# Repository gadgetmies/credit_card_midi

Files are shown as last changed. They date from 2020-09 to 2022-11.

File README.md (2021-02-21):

# Credit Card MIDI Controllers

Arduino based, credit card sized, capacitive touch sensing MIDI controllers.

Very much a work in progress. Contributions welcomed 😊!

USB board connector design by @Pinuct: https://github.com/Pinuct/Eagle_PCB_USB_connectors

More info: https://hackaday.io/project/177099-credit-card-midi

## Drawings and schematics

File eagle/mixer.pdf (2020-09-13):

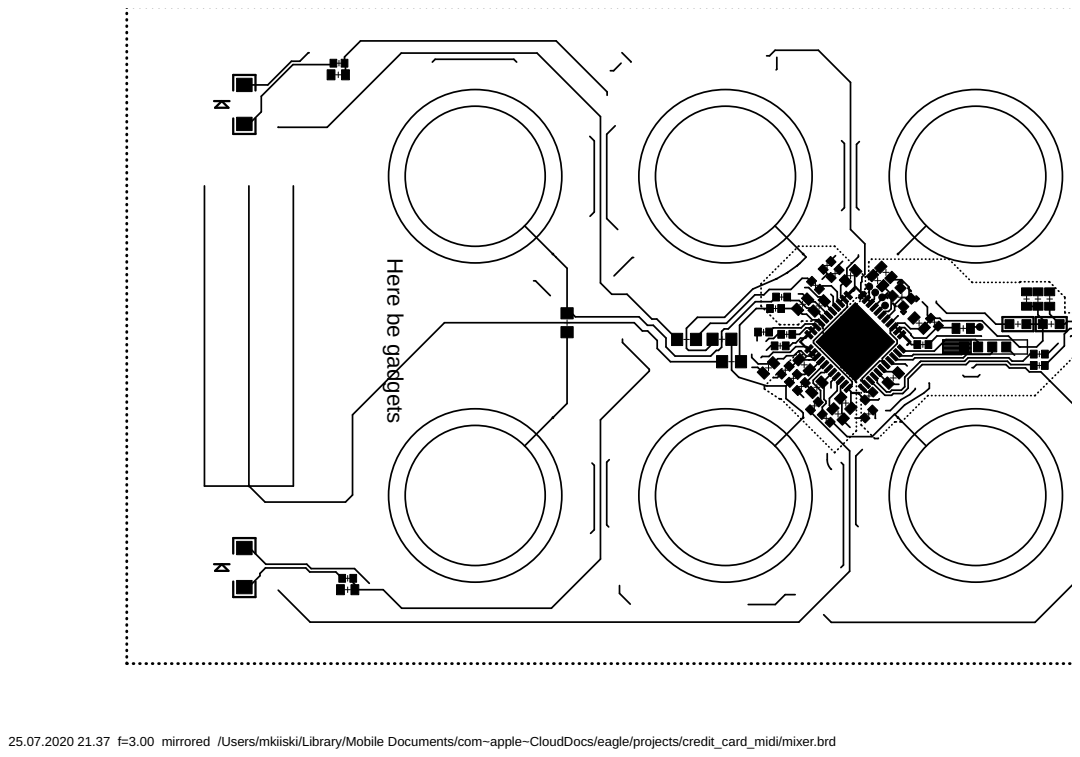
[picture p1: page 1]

25.07.2020 21.37 f=3.00 mirrored /Users/mkiiski/Library/Mobile Documents/com~apple~CloudDocs/eagle/projects/credit_card_midi/mixer.brd

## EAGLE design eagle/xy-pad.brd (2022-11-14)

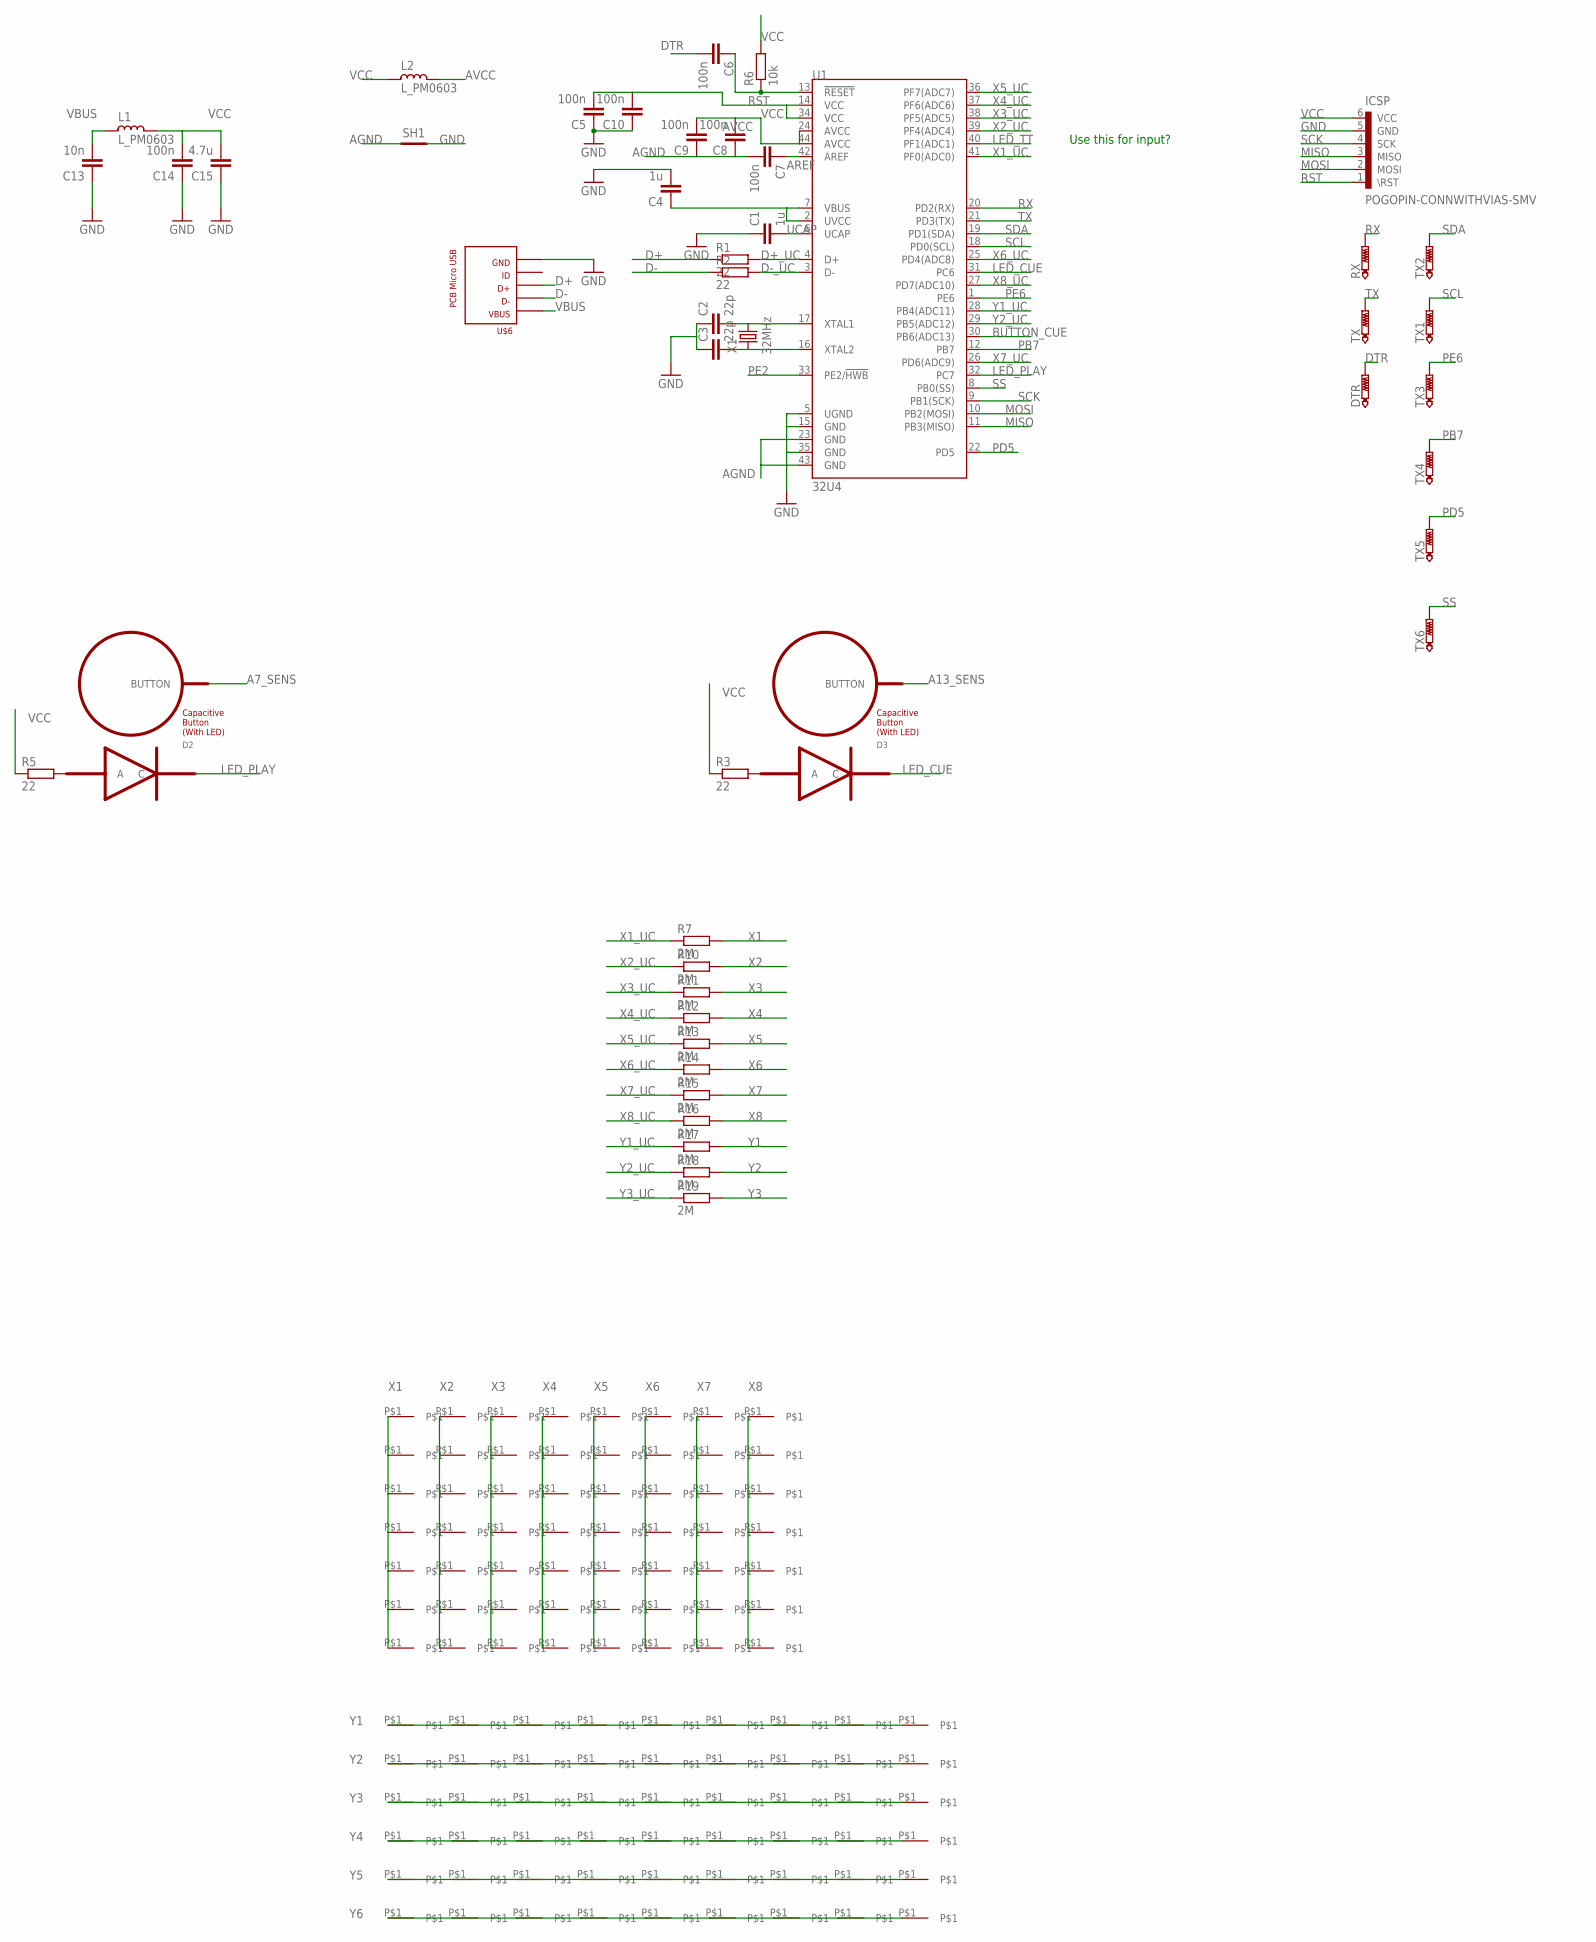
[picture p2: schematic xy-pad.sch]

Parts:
C1, C4: 1u; C0402
C2, C3: 22p; C0402
C5, C6, C7, C8, C9, C10, C14: 100n; C0402
C13: 10n; C0402
C15: 4.7u; C0402
D2, D3: LED_BUTTON
DTR: PTR1TP06R; TP06R
ICSP: POGOPIN-CONNWITHVIAS-SMV; POGOPROG-CONN-OH-SMALLERVIAS
L1, L2: L_PM0603; PM0603
R1, R2, R3, R5: 22; R0402
R6: 10k; R0402
R7, R10, R11, R12, R13, R14, R15, R16, R17, R18, R19: 2M; R0402
RX: PTR1TP06R; TP06R
SH1: SHORT; SHORT_TOP-6
TX, TX1, TX2, TX3, TX4, TX5, TX6: PTR1TP06R; TP06R
U1: 32U4; QFN-44
U$1, U$11, U$12, U$13, U$14, U$15, U$16, U$17, U$18, U$19, U$20, U$21, U$22, U$23, U$24, U$25, U$26, U$27, U$28, U$29, U$30, U$31, U$32, U$33, U$34, U$35, U$36, U$37, U$38, U$39, U$40, U$41, U$42, U$43, U$44, U$45, U$46, U$47, U$48, U$49, U$64, U$65, U$66, U$67, U$68, U$69, U$70, U$71, U$72, U$73, U$74, U$75, U$76, U$77, U$78, U$79, U$80, U$81, U$82, U$83, U$84, U$85, U$86, U$87, U$88, U$89, U$90, U$91, U$92, U$93, U$94, U$95, U$96, U$97, U$98, U$99, U$100, U$101, U$102, U$103, U$104, U$105: XY_PAD; DIAMOND_PAD
U$2, U$3, U$4, U$5, U$7, U$8, U$9, U$10, U$50, U$51, U$52, U$53, U$54, U$55, U$56, U$57, U$58, U$59, U$60, U$61, U$62, U$63, U$106, U$107, U$108, U$109, U$110, U$111: XY_PADTRIANGLE; TRIANGLE_PAD
U$6: PCB_MICRO_USB_BSS_2; USB_TYPE_B_SS_2
X1: 32MHz; CRYSTAL-SMD-2.0X1.6MM

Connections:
A7_SENS: D2.BUTTON
A13_SENS: D3.BUTTON
AGND: C7.2, C8.1, C9.1, SH1.1, U1.23 (GND), U1.43 (GND)
AREF: C7.1, U1.42 (AREF)
AVCC: C8.2, C9.2, L2.1, U1.24 (AVCC), U1.44 (AVCC)
BUTTON_CUE: U1.30 (PB6(ADC13))
D+: R1.1, U$6.3
D+_UC: R1.2, U1.4 (D+)
D-: R2.1, U$6.2
D-_UC: R2.2, U1.3 (D-)
DTR: C6.2, DTR.TP
GND: C1.1, C2.1, C3.1, C4.2, C5.1, C10.1, C13.1, C14.1, C15.1, ICSP.5 (GND), SH1.2, U1.5 (UGND), U1.15 (GND), U1.35 (GND), U$6.5
LED_CUE: D3.C, U1.31 (PC6)
LED_PLAY: D2.C, U1.32 (PC7)
LED_TT: U1.40 (PF1(ADC1))
MISO: ICSP.3 (MISO), U1.11 (PB3(MISO))
MOSI: ICSP.2 (MOSI), U1.10 (PB2(MOSI))
unnamed: D3.A, R3.2
unnamed: C2.2, U1.17 (XTAL1), X1.3 (2)
unnamed: C3.2, U1.16 (XTAL2), X1.1
unnamed: D2.A, R5.2
PB7: TX4.TP, U1.12 (PB7)
PD5: TX5.TP, U1.22 (PD5)
PE2: U1.33 (PE2/!HWB)
PE6: TX3.TP, U1.1 (PE6)
RST: C6.1, ICSP.1 (\RST), R6.1, U1.13 (!RESET)
RX: RX.TP, U1.20 (PD2(RX))
SCK: ICSP.4 (SCK), U1.9 (PB1(SCK))
SCL: TX1.TP, U1.18 (PD0(SCL))
SDA: TX2.TP, U1.19 (PD1(SDA))
SS: TX6.TP, U1.8 (PB0(SS))
TX: TX.TP, U1.21 (PD3(TX))
UCAP: C1.2, U1.6 (UCAP)
VBUS: C13.2, L1.2, U$6.1
VCC: C4.1, C5.2, C10.2, C14.2, C15.2, ICSP.6 (VCC), L1.1, L2.2, R3.1, R5.1, R6.2, U1.2 (UVCC), U1.7 (VBUS), U1.14 (VCC), U1.34 (VCC)
X1: R7.2, U$1.P$1, U$2.P$1, U$18.P$1, U$26.P$1, U$34.P$1, U$42.P$1, U$50.P$1
X1_UC: R7.1, U1.41 (PF0(ADC0))
X2: R10.2, U$3.P$1, U$11.P$1, U$19.P$1, U$27.P$1, U$35.P$1, U$43.P$1, U$51.P$1
X2_UC: R10.1, U1.39 (PF4(ADC4))
X3: R11.2, U$4.P$1, U$12.P$1, U$20.P$1, U$28.P$1, U$36.P$1, U$44.P$1, U$52.P$1
X3_UC: R11.1, U1.38 (PF5(ADC5))
X4: R12.2, U$5.P$1, U$13.P$1, U$21.P$1, U$29.P$1, U$37.P$1, U$45.P$1, U$53.P$1
X4_UC: R12.1, U1.37 (PF6(ADC6))
X5: R13.2, U$7.P$1, U$14.P$1, U$22.P$1, U$30.P$1, U$38.P$1, U$46.P$1, U$54.P$1
X5_UC: R13.1, U1.36 (PF7(ADC7))
X6: R14.2, U$8.P$1, U$15.P$1, U$23.P$1, U$31.P$1, U$39.P$1, U$47.P$1, U$55.P$1
X6_UC: R14.1, U1.25 (PD4(ADC8))
X7: R15.2, U$9.P$1, U$16.P$1, U$24.P$1, U$32.P$1, U$40.P$1, U$48.P$1, U$56.P$1
X7_UC: R15.1, U1.26 (PD6(ADC9))
X8: R16.2, U$10.P$1, U$17.P$1, U$25.P$1, U$33.P$1, U$41.P$1, U$49.P$1, U$57.P$1
X8_UC: R16.1, U1.27 (PD7(ADC10))
Y1: R17.2, U$63.P$1, U$69.P$1, U$75.P$1, U$81.P$1, U$87.P$1, U$93.P$1, U$99.P$1, U$105.P$1, U$111.P$1
Y1_UC: R17.1, U1.28 (PB4(ADC11))
Y2: R18.2, U$62.P$1, U$68.P$1, U$74.P$1, U$80.P$1, U$86.P$1, U$92.P$1, U$98.P$1, U$104.P$1, U$110.P$1
Y2_UC: R18.1, U1.29 (PB5(ADC12))
Y3: R19.2, U$61.P$1, U$67.P$1, U$73.P$1, U$79.P$1, U$85.P$1, U$91.P$1, U$97.P$1, U$103.P$1, U$109.P$1
Y3_UC: R19.1
Y4: U$60.P$1, U$66.P$1, U$72.P$1, U$78.P$1, U$84.P$1, U$90.P$1, U$96.P$1, U$102.P$1, U$108.P$1
Y5: U$59.P$1, U$65.P$1, U$71.P$1, U$77.P$1, U$83.P$1, U$89.P$1, U$95.P$1, U$101.P$1, U$107.P$1
Y6: U$58.P$1, U$64.P$1, U$70.P$1, U$76.P$1, U$82.P$1, U$88.P$1, U$94.P$1, U$100.P$1, U$106.P$1

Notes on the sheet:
Use this for input?

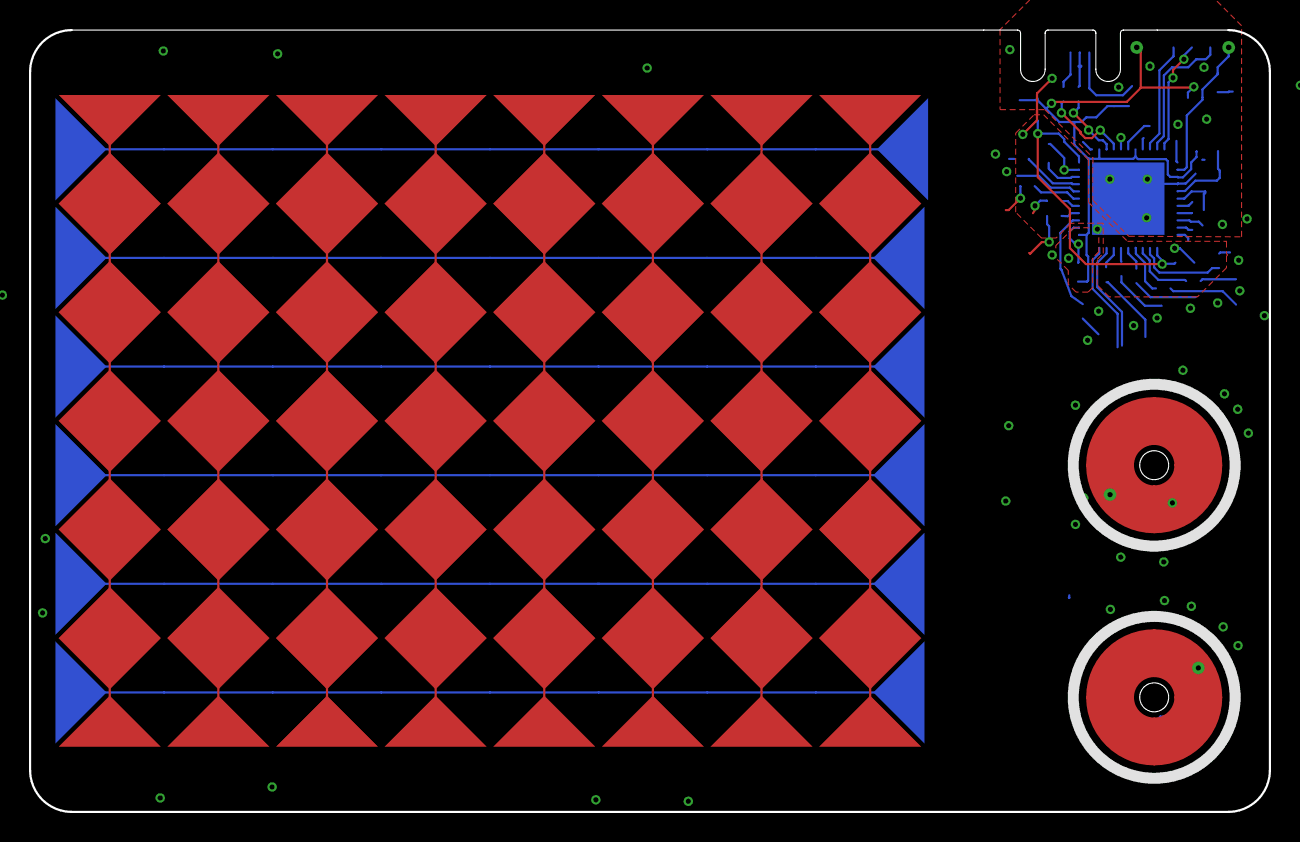
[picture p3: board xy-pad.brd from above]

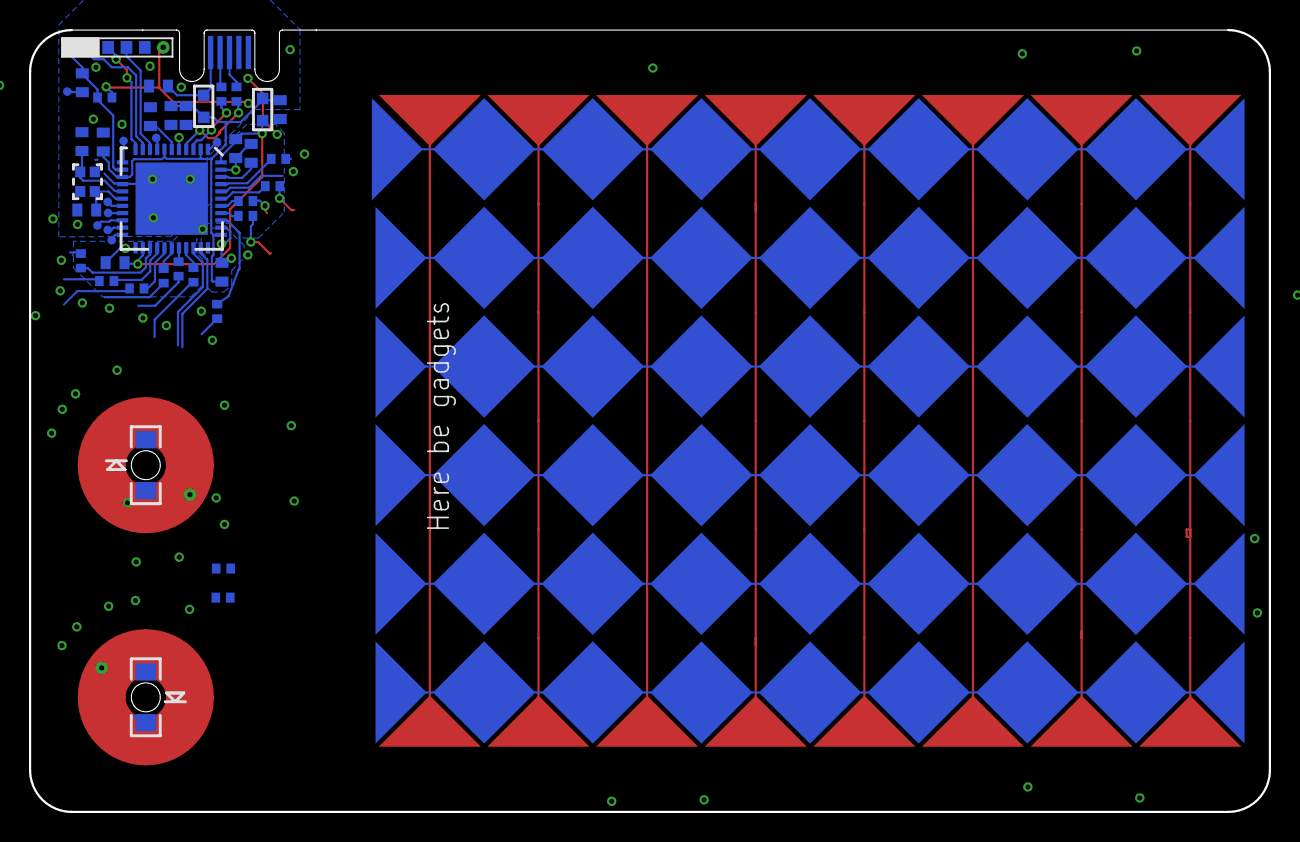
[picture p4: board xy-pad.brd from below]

Board: 2 copper layers, 85.6 x 54.0 mm, 157 parts (98 on the bottom side), 54 nets.

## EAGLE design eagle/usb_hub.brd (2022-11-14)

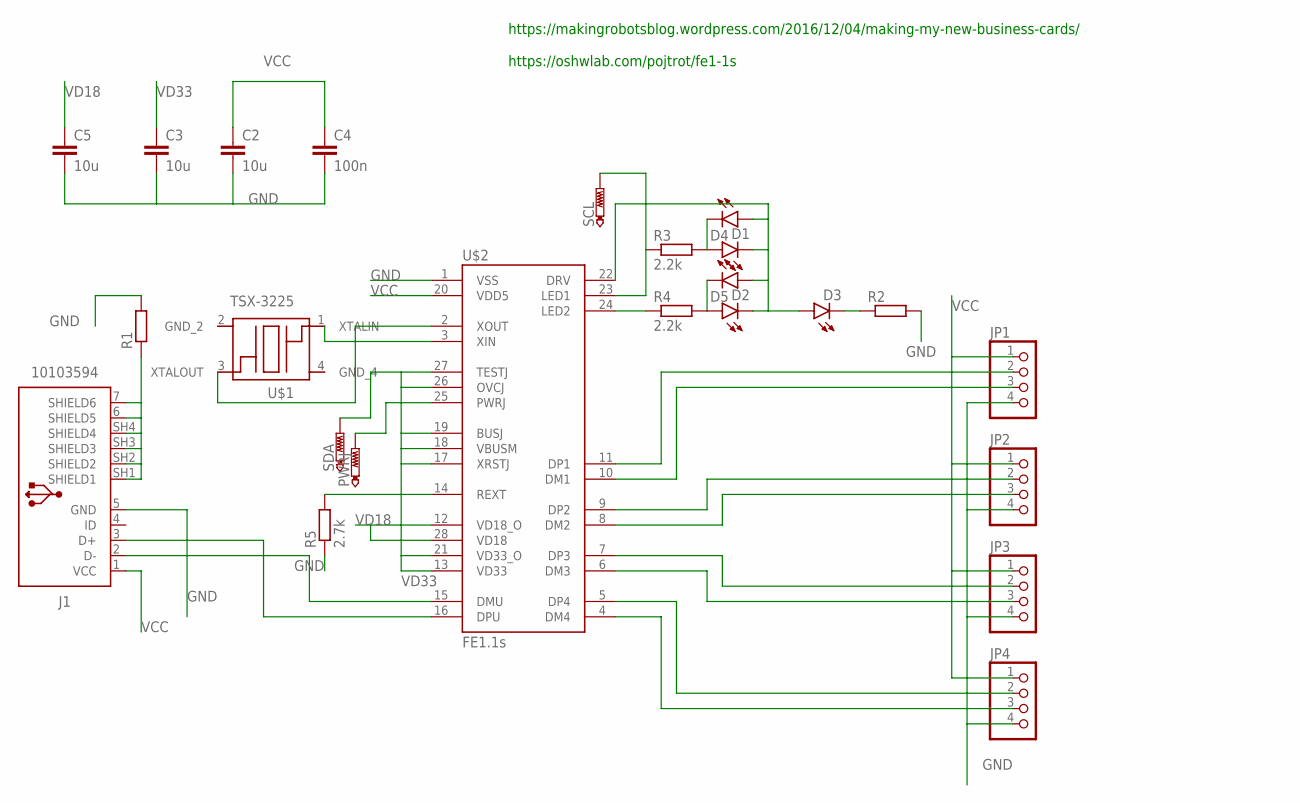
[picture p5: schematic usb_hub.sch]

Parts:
C2, C3, C5: 10u; C0805
C4: 100n; C0603
D1, D2, D3, D4, D5: LEDCHIP-LED0603; CHIP-LED0603
J1: 10103594
JP1, JP2, JP3, JP4: PINHD-1X4; 1X04
PWRJ: PTR1B1,27; B1,27
R1, R2: R-EU_R0603; R0603
R3, R4: 2.2k; R0603
R5: 2.7k; R0603
SCL: PTR1B1,27; B1,27
SDA: PTR1B1,27; B1,27
U$1: TSX-3225
U$2: FE1.1S; FE1.1S_SSOP-28

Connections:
GND: C2.2, C3.2, C4.2, C5.2, J1.5 (GND), JP1.4, JP2.4, JP3.4, JP4.4, R1.2, R2.2, R5.1, U$2.1 (VSS)
unnamed: J1.3 (D+), U$2.16 (DPU)
unnamed: J1.2 (D-), U$2.15 (DMU)
unnamed: U$1.1 (XTALIN), U$2.3 (XIN)
unnamed: U$1.3 (XTALOUT), U$2.2 (XOUT)
unnamed: D1.A, D4.C, R3.2
unnamed: D2.A, D5.C, R4.2
unnamed: JP4.3, U$2.4 (DM4)
unnamed: JP4.2, U$2.5 (DP4)
unnamed: JP3.3, U$2.6 (DM3)
unnamed: JP3.2, U$2.7 (DP3)
unnamed: JP2.3, U$2.8 (DM2)
unnamed: JP2.2, U$2.9 (DP2)
unnamed: JP1.3, U$2.10 (DM1)
unnamed: JP1.2, U$2.11 (DP1)
unnamed: R4.1, U$2.24 (LED2)
unnamed: D3.C, R2.1
unnamed: R3.1, SCL.TP, U$2.23 (LED1)
unnamed: D1.C, D2.C, D3.A, D4.A, D5.A, U$2.22 (DRV)
unnamed: PWRJ.TP, U$2.25 (PWRJ)
unnamed: R5.2, U$2.14 (REXT)
SHIELD2: J1.6 (SHIELD5), J1.7 (SHIELD6), J1.SH1 (SHIELD1), J1.SH2 (SHIELD2), J1.SH3 (SHIELD3), J1.SH4 (SHIELD4), R1.1
VCC: C2.1, C4.1, J1.1 (VCC), JP1.1, JP2.1, JP3.1, JP4.1, U$2.20 (VDD5)
VD18: C5.1, U$2.12 (VD18_O), U$2.28 (VD18)
VD33: C3.1, SDA.TP, U$2.13 (VD33), U$2.17 (XRSTJ), U$2.18 (VBUSM), U$2.19 (BUSJ), U$2.21 (VD33_O), U$2.26 (OVCJ), U$2.27 (TESTJ)

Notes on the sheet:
https://makingrobotsblog.wordpress.com/2016/12/04/making-my-new-business-cards/ https://oshwlab.com/pojtrot/fe1-1s

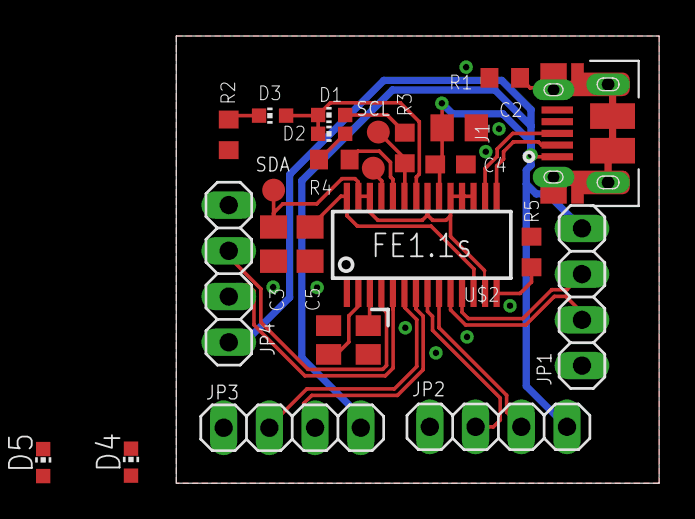
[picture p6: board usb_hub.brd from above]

Board: 2 copper layers, 26.8 x 24.8 mm, 24 parts (0 on the bottom side), 25 nets.

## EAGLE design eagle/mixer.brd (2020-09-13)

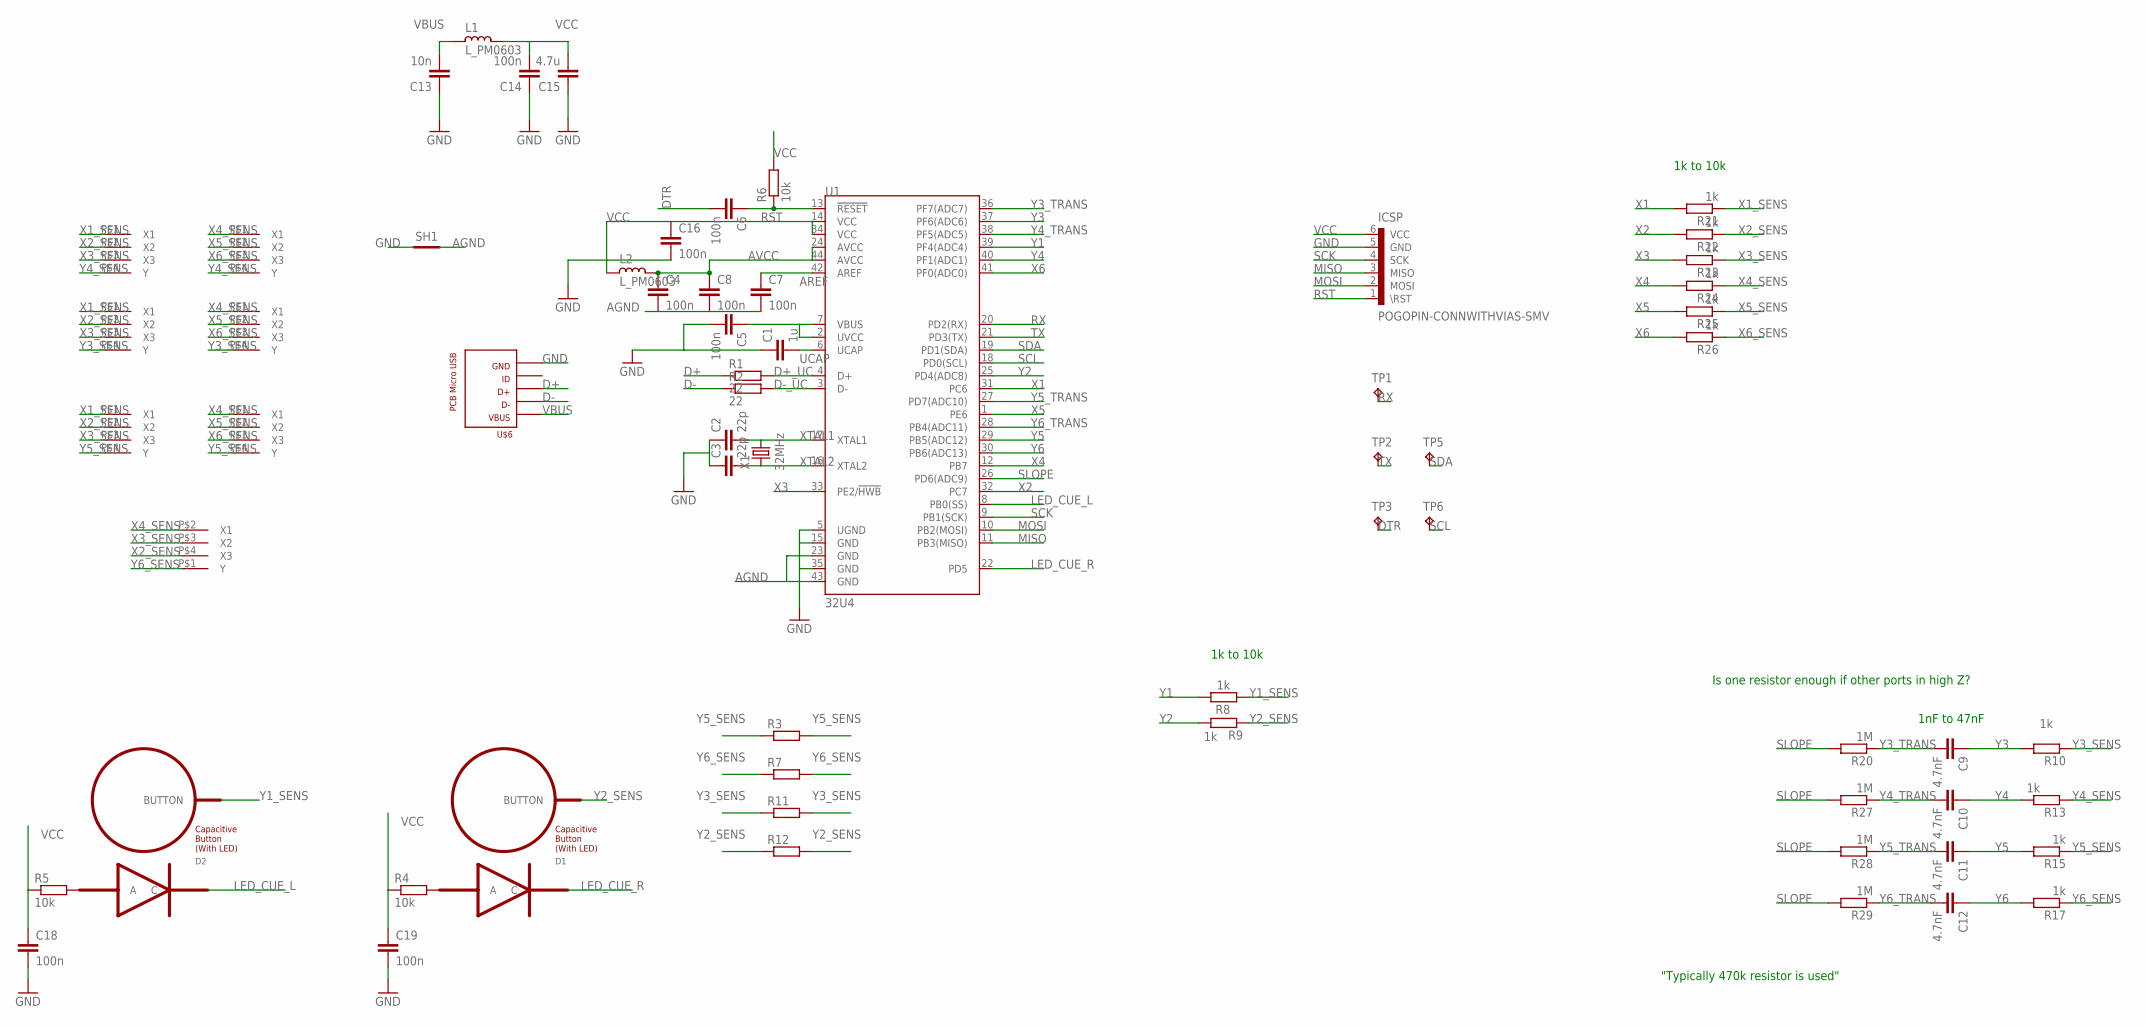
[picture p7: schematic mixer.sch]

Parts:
C1: 1u; C0402
C2, C3: 22p; C0402
C4, C5, C6, C7, C8, C14, C16, C18, C19: 100n; C0402
C9, C10, C11, C12: 4.7nF; C0402
C13: 10n; C0402
C15: 4.7u; C0402
D1, D2: LED_BUTTON
ICSP: POGOPIN-CONNWITHVIAS-SMV; POGOPROG-CONN-OH-SMALLERVIAS
L1, L2: L_PM0603; PM0603
R1, R2: 22; R0402
R3, R7, R11, R12: R-EU_R0603; R0603
R4, R5, R6: 10k; R0402
R8, R9, R10, R13, R15, R17, R21, R22, R23, R24, R25, R26: 1k; R0402
R20, R27, R28, R29: 1M; R0402
SH1: SHORT; SHORT_TOP-6
TP1, TP2, TP3, TP5, TP6: TPTP06R; TP06R
U1: 32U4; QFN-44
U$1, U$2, U$3, U$4, U$5, U$7: EQ_MUTUAL; SMALL_EQ
U$6: PCB_MICRO_USB_BSS_2; USB_TYPE_B_SS_2
U$8: SLIDER
X1: 32MHz; CRYSTAL-SMD-2.0X1.6MM

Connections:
AGND: C4.2, C7.2, C8.2, SH1.2, U1.23 (GND), U1.43 (GND)
AREF: C7.1, U1.42 (AREF)
AVCC: C4.1, C8.1, L2.1, U1.24 (AVCC), U1.44 (AVCC)
D+: R1.1, U$6.3
D+_UC: R1.2, U1.4 (D+)
D-: R2.1, U$6.2
D-_UC: R2.2, U1.3 (D-)
DTR: C6.2, TP3.TP
GND: C1.1, C2.1, C3.1, C5.2, C13.1, C14.1, C15.1, C16.2, C18.2, C19.2, ICSP.5 (GND), SH1.1, U1.5 (UGND), U1.15 (GND), U1.35 (GND), U$6.5
LED_CUE_L: D2.C, U1.8 (PB0(SS))
LED_CUE_R: D1.C, U1.22 (PD5)
MISO: ICSP.3 (MISO), U1.11 (PB3(MISO))
MOSI: ICSP.2 (MOSI), U1.10 (PB2(MOSI))
unnamed: D1.A, R4.2
unnamed: D2.A, R5.2
RST: C6.1, ICSP.1 (\RST), R6.1, U1.13 (!RESET)
RX: TP1.TP, U1.20 (PD2(RX))
SCK: ICSP.4 (SCK), U1.9 (PB1(SCK))
SCL: TP6.TP, U1.18 (PD0(SCL))
SDA: TP5.TP, U1.19 (PD1(SDA))
SLOPE: R20.2, R27.2, R28.2, R29.2, U1.26 (PD6(ADC9))
TX: TP2.TP, U1.21 (PD3(TX))
UCAP: C1.2, U1.6 (UCAP)
VBUS: C13.2, L1.2, U$6.1
VCC: C5.1, C14.2, C15.2, C16.1, C18.1, C19.1, ICSP.6 (VCC), L1.1, L2.2, R4.1, R5.1, R6.2, U1.2 (UVCC), U1.7 (VBUS), U1.14 (VCC), U1.34 (VCC)
X1: R21.2, U1.31 (PC6)
X1_SENS: R21.1, U$1.P$1 (X1), U$2.P$1 (X1), U$3.P$1 (X1)
X2: R22.2, U1.32 (PC7)
X2_SENS: R22.1, U$1.P$2 (X2), U$2.P$2 (X2), U$3.P$2 (X2), U$8.P$4 (X3)
X3: R23.2, U1.33 (PE2/!HWB)
X3_SENS: R23.1, U$1.P$3 (X3), U$2.P$3 (X3), U$3.P$3 (X3), U$8.P$3 (X2)
X4: R24.2, U1.12 (PB7)
X4_SENS: R24.1, U$4.P$1 (X1), U$5.P$1 (X1), U$7.P$1 (X1), U$8.P$2 (X1)
X5: R25.2, U1.1 (PE6)
X5_SENS: R25.1, U$4.P$2 (X2), U$5.P$2 (X2), U$7.P$2 (X2)
X6: R26.2, U1.41 (PF0(ADC0))
X6_SENS: R26.1, U$4.P$3 (X3), U$5.P$3 (X3), U$7.P$3 (X3)
XTAL1: C2.2, U1.17 (XTAL1), X1.3 (2)
XTAL2: C3.2, U1.16 (XTAL2), X1.1
Y1: R8.2, U1.39 (PF4(ADC4))
Y1_SENS: D2.BUTTON, R8.1
Y2: R9.2, U1.25 (PD4(ADC8))
Y2_SENS: D1.BUTTON, R9.1, R12.1, R12.2
Y3: C9.1, R10.2, U1.37 (PF6(ADC6))
Y3_SENS: R10.1, R11.1, R11.2, U$2.P$4 (Y), U$5.P$4 (Y)
Y3_TRANS: C9.2, R20.1, U1.36 (PF7(ADC7))
Y4: C10.1, R13.2, U1.40 (PF1(ADC1))
Y4_SENS: R13.1, U$1.P$4 (Y), U$4.P$4 (Y)
Y4_TRANS: C10.2, R27.1, U1.38 (PF5(ADC5))
Y5: C11.1, R15.2, U1.29 (PB5(ADC12))
Y5_SENS: R3.1, R3.2, R15.1, U$3.P$4 (Y), U$7.P$4 (Y)
Y5_TRANS: C11.2, R28.1, U1.27 (PD7(ADC10))
Y6: C12.1, R17.2, U1.30 (PB6(ADC13))
Y6_SENS: R7.1, R7.2, R17.1, U$8.P$1 (Y)
Y6_TRANS: C12.2, R29.1, U1.28 (PB4(ADC11))

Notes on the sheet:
Is one resistor enough if other ports in high Z?
"Typically 470k resistor is used"
1nF to 47nF
1k to 10k

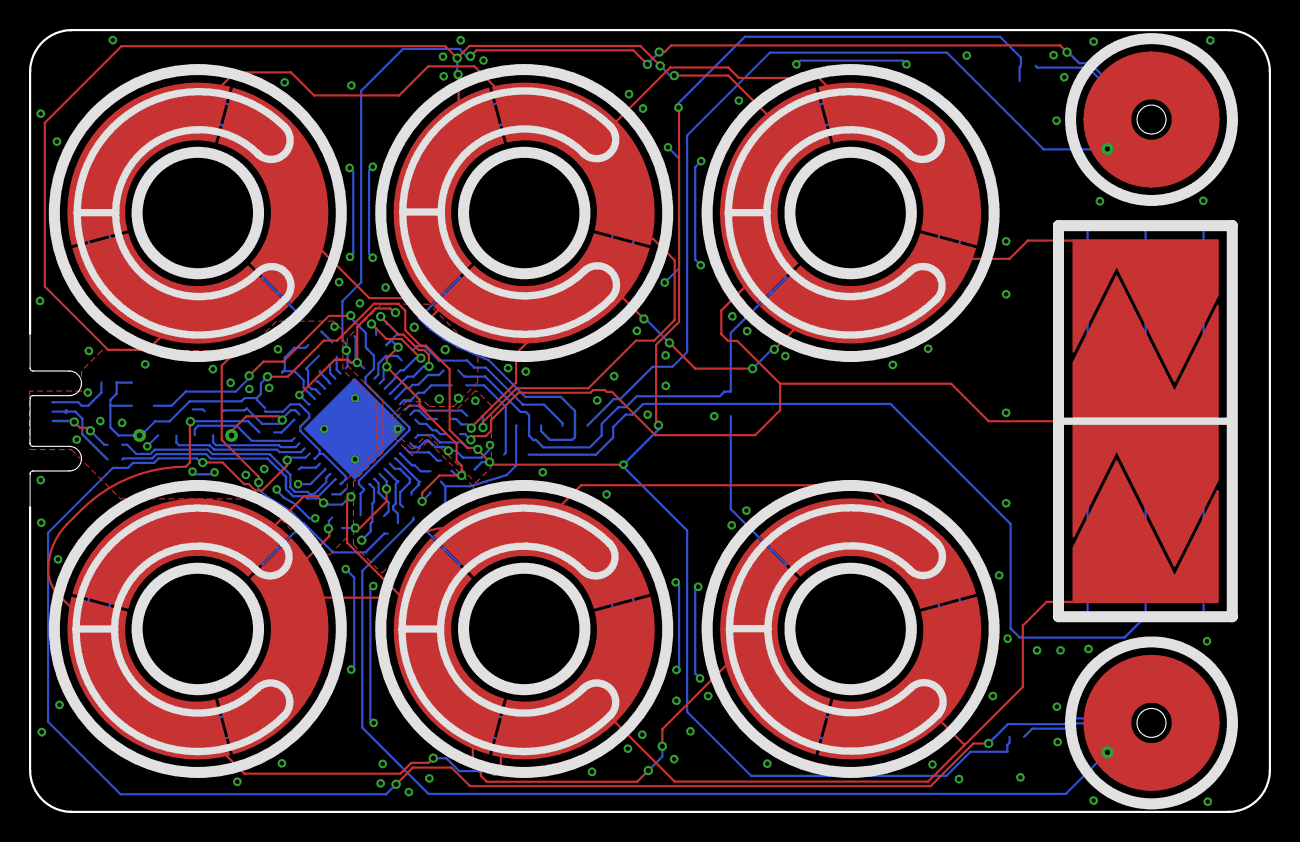
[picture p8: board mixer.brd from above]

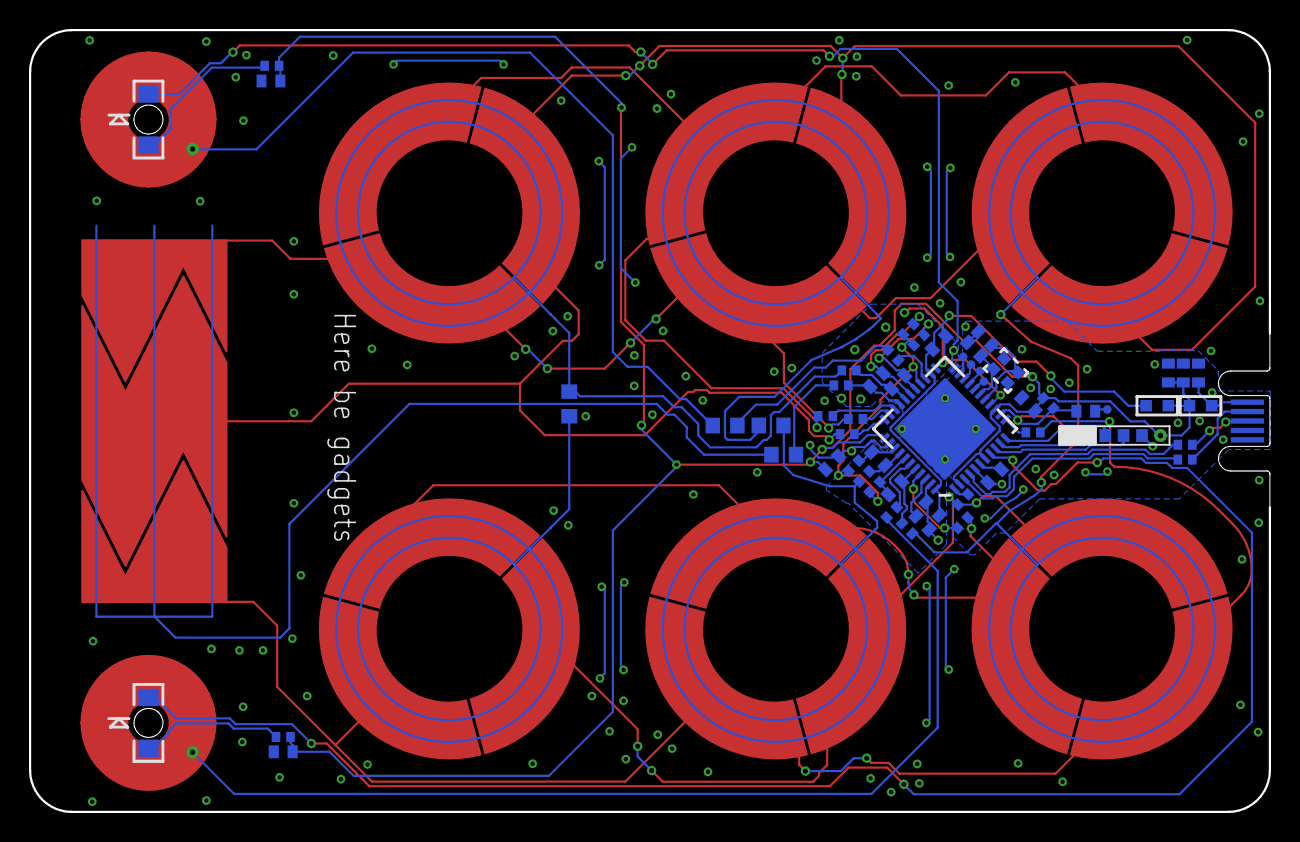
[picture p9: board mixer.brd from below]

Board: 2 copper layers, 85.6 x 54.0 mm, 64 parts (54 on the bottom side), 55 nets.

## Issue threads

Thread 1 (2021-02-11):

Add license information

vazhnov, 2021-02-11:
Hello!

I found link to this project from https://www.hackster.io/news/this-clever-credit-card-sized-dj-console-aims-to-have-you-cutting-and-mixing-on-the-move-ce35b8ec55cd

Could you please add information about license of this repository — is it allowed to copy, change and use the code and board schematic files in any purpose?
It would be great to see any popular open source license.

gadgetmies, 2021-02-21:
Hi!

Thank you for opening this issue! I totally forgot to add a license earlier. I now added GPLv3 LICENSE file. Hope this works for you. If not, please let me know!

Closed 2021-02-21.

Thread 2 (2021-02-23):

Printing the PCB

ligi, 2021-02-23:
Hi,

sorry - I found no contact somewhere so need to ask here: would it make sense to order the current PCB design or do you currently work on the next iteration? Would like to try it out but missing a bit of info if it makes sense currently

gadgetmies, 2021-02-24:
Hi,

This is a good place to ask!

I have not tested the boards fully yet, so there might be (and probably are) mistakes in the design. What I can say for sure at this point is that the capacitive wheel and two out of the three buttons on the turntable board work. I am not actively working on a new version of the board and am not aware of design issues, but as said I have not really tested the boards that well yet.

ligi, 2021-02-24:
cool - can you let me know when you tested the board fully? Would like to print one for my bicycle-sound (https://ligi.de/sound) - but can wait a bit for more tests to see if it makes sense to print them.

gadgetmies, 2021-02-24:
Sure! I will post a message in this issue when I have further details.

PS: Nice project you have there 👍!

ligi, 2021-02-24:
cool - looking forward - keep up the good work!

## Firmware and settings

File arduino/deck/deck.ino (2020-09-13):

#include <pitchToFrequency.h>
#include <pitchToNote.h>
#include <frequencyToNote.h>
#include <MIDIUSB.h>

#include <TouchWheel.h>
#include <TouchSlider.h>
#include <AdcTouchChannel.h>

#include <ADCTouch.h>

const byte CMF_DECK_BUTTON_TT = 0;
const byte CMF_DECK_BUTTON_PLAY = 7;
const byte CMF_DECK_BUTTON_CUE = 13;

const byte CMF_DECK_TT1 = 6;
const byte CMF_DECK_TT2 = 5;
const byte CMF_DECK_TT3 = 4;

const byte CMF_DECK_PITCH1 = 12;
const byte CMF_DECK_PITCH2 = 11;
const byte CMF_DECK_PITCH3 = 10;
const byte CMF_DECK_PITCH4 = 9;
const byte CMF_DECK_PITCH5 = 8;

TouchWheel tw(CMF_DECK_TT1, CMF_DECK_TT2, CMF_DECK_TT3);

int ref0, ref1, ref2;     //reference values to remove offset
int refTT, refPlay, refCue;
int max0, max1, max2;
bool led0On, led1On, led2On = false;

byte mode = 0;
byte largest = 0;

void setup() {
  Serial.begin(115200);
  pinMode(CM_DECK_LED_PLAY, OUTPUT);
  pinMode(CM_DECK_LED_CUE, OUTPUT);
  pinMode(CM_DECK_LED_TT, OUTPUT);

  digitalWrite(CM_DECK_LED_PLAY, HIGH);
  digitalWrite(CM_DECK_LED_CUE, HIGH);
  digitalWrite(CM_DECK_LED_TT, HIGH);

//  tw.setFastAdc(); //hack the ADC to run 8x faster
//  tw.calibrate(); //run this when no one is touching sensor

  delay(1000);
  
  ref0 = 773; //ADCTouch.read(CMF_DECK_TT1, 500);    //create reference values to 
  ref1 = 760; //ADCTouch.read(CMF_DECK_TT2, 500);    //account for the capacitance of the pad
  ref2 = 769; //ADCTouch.read(CMF_DECK_TT3, 500);

  refTT = 0; //ADCTouch.read(CMF_DECK_BUTTON_TT, 41);   //no second parameter
  refPlay = 0; //ADCTouch.read(CMF_DECK_BUTTON_PLAY, 36);   //   --> 100 samples
  refCue = 0; //ADCTouch.read(CMF_DECK_BUTTON_CUE, 30);
}

void loop() { 
//  handleButtons();
  handleWheel();
//  handleSlider();
//  handleTouchWheel();
}

boolean isTouching = false;

void handleTouchWheel() {
  int wheel = tw.scan();  //call this frequently and check the results
  if (wheel > 0) { //positive indicates one direction
    Serial.println("Wheel moved up!");
  } else if (wheel < 0) { //negative the other direction
    Serial.println("Wheel moved down!");
  }

  if (tw.isTouching() != isTouching) {
    isTouching = tw.isTouching();
    Serial.print("Wheel is touching: ");
    Serial.println(isTouching);
  }
}

byte maximum(byte a, byte b, byte c)
{
   int max = ( a < b ) ? b : a;
   return ( ( max < c ) ? c : max );
}

int readf(byte adcChannel, byte digitalPin, int samples = 100)
{
  long _value = 0;
  for(int _counter = 0; _counter < samples; _counter ++)
  {
    // set the analog pin as an input pin with a pullup resistor
    // this will start charging the capacitive element attached to that pin
    pinMode(digitalPin, INPUT_PULLUP);
    
    // connect the ADC input and the internal sample and hold capacitor to ground to discharge it
    ADMUX |=   0b11111;

    // start the conversion
    ADCSRA |= (1 << ADSC);

    // ADSC is cleared when the conversion finishes
    while((ADCSRA & (1 << ADSC)));

    pinMode(digitalPin, INPUT);
    _value += analogRead(adcChannel);
  }
  return _value / samples;
}

bool playPressed = false;
bool cuePressed = false;
bool ttPressed = false;

void handleButtons() {
  int value0 = ADCTouch.read(CMF_DECK_BUTTON_TT, 41);   //no second parameter
  int value1 = ADCTouch.read(CMF_DECK_BUTTON_PLAY, 36);   //   --> 100 samples
//  int value2 = ADCTouch.read(CMF_DECK_BUTTON_CUE, 30);
  
//  value0 -= refTT;       //remove offset
//  value1 -= refPlay;
//  value2 -= refCue;
//
//  Serial.print(value0);             //send actual reading
//  Serial.print(" ");
//  Serial.println(value1);
//  Serial.print(" ");
//  Serial.println(value2);
  
  if (value0 > 40 && ttPressed == false) {
    ttPressed = true;
    noteOn(0, 1, 127);
  } else if (value0 < 30 && ttPressed) {
    ttPressed = false;
    noteOff(0, 1, 127);
  }
  
  if (value1 > 40 && cuePressed == false) {
    cuePressed = true;
    noteOn(0, 2, 127);
  } else if (value1 < 30 && cuePressed) {
    cuePressed = false;
    noteOff(0, 2, 127);
  }

  MidiUSB.flush();
}

void noteOn(byte channel, byte pitch, byte velocity) {
  midiEventPacket_t noteOn = {0x09, 0x90 | channel, pitch, velocity};
  MidiUSB.sendMIDI(noteOn);
}

void noteOff(byte channel, byte pitch, byte velocity) {
  midiEventPacket_t noteOff = {0x08, 0x80 | channel, pitch, velocity};
  MidiUSB.sendMIDI(noteOff);
}

void controlChange(byte channel, byte control, byte value) {
  midiEventPacket_t event = {0x0B, 0xB0 | channel, control, value};
  MidiUSB.sendMIDI(event);
}

int previousValue = 0;
bool touching = false;
const int wheelMax = 666;
const int wheelMin = 4;
const int wheelRange = wheelMax - wheelMin;

void handleWheel() {
  int value0 = readf(CMF_DECK_TT1, 37);   //no second parameter
  int value2 = readf(CMF_DECK_TT2, 38);   //   --> 100 samples
  int value1 = readf(CMF_DECK_TT3, 39);
  
  value0 -= ref0;       //remove offset
  value1 -= ref1;
  value2 -= ref2;
  
  if (value0 > 50 || value1 > 50 || value2 > 50) {
    if (value0 > value1) {
      if (value0 > value2) {
        largest = 0;
      } else {
        largest = 2;
      }
    } else {
      if (value1 > value2) {
        largest = 1;
      } else {
        largest = 2;
      }
    }
  } else {
    largest = 4;
  }

  int value = 0;

  switch (largest) {
    case 0: {
      value = 100 + (value1 - value2) * 120 / (value0);
      break;
    }
    case 1: {
      value = 350 - (value0 - value2) * 120 / (value1);
      break;
    }
    case 2: {
      value = 570 - (value1 - value0) * 120 / (value2);
      break;
    }
    case 4: {
      if (touching) {
        touching = false;
        noteOff(0, 0, 127);
        MidiUSB.flush();
      }
      return;
    }
  }
  Serial.print(value0);
  Serial.print('\t');
  Serial.print(value1);
  Serial.print('\t');
  Serial.print(value2);
  Serial.print('\t');
  Serial.print(value);
  Serial.print('\t');
  Serial.print(previousValue);
  Serial.print('\t');
  Serial.println(previousValue - value);

  byte diff = abs(previousValue - value) % 670;

  if (!touching) {
    touching = true;
    previousValue = value;
    noteOn(0, 0, 127);
    MidiUSB.flush();
  } else if (diff > 10 && value != previousValue) {
//    for (byte i = 0; i < diff / 10; ++i) {
//      controlChange(0, 0, value > previousValue ? 1 : 127);
//    }
    MidiUSB.flush();
    previousValue = value;
  }
}

void handleSlider() {
  int value0 = readf(CMF_DECK_PITCH1, 29);   //no second parameter
  int value1 = readf(CMF_DECK_PITCH2, 28);   //   --> 100 samples
  int value2 = readf(CMF_DECK_PITCH3, 27);
  int value3 = readf(CMF_DECK_PITCH4, 26);   //no second parameter
  int value4 = readf(CMF_DECK_PITCH5, 25);   //   --> 100 samples

  Serial.print(value0);             //send actual reading
  Serial.print(" ");
  Serial.print(value1);
  Serial.print(" ");
  Serial.print(value2);
  Serial.print(" ");
  Serial.print(value3);
  Serial.print(" ");
  Serial.println(value4);
}

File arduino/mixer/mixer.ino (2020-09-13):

void setup() {
  pinMode(CM_MIXER_LED_CUE_L, OUTPUT);
  pinMode(CM_MIXER_LED_CUE_R, OUTPUT);
}

void loop() {
  digitalWrite(CM_MIXER_LED_CUE_L, HIGH);
  digitalWrite(CM_MIXER_LED_CUE_R, HIGH);
  delay(1000);
  digitalWrite(CM_MIXER_LED_CUE_L, LOW);
  digitalWrite(CM_MIXER_LED_CUE_R, LOW);
  delay(1000);
}

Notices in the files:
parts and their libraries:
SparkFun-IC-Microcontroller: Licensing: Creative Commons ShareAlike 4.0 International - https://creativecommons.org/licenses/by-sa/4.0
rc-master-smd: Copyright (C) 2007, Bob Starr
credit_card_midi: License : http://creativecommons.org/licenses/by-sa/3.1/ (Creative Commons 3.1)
